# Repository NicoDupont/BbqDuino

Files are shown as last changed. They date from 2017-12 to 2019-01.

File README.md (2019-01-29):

## Arduino BbqDuino

Author : Nicolas Dupont  
Last Update : 14/01/2019  
Current state : **Prototype finished**  

The goal is to read, store and display the temperature of a barbecue/grill to follow the cooking.  
I hope it will be a very good friend for cooking sessions on my gaz barbecue.  

**To do List for final v1 ! :**  

1. Power supply the arduino from power bank
2. Electric card for integration
3. Fritzing
4. Make integration into a box
5. improve the arduino code and web app code
6. Add ifttt alert

**Features :**

- A WebApp to manage and monitor the cooking session.(the web app is designed to have just the necessary things)
- Monitor on the lcd the temperatures and the time ("partial" time can be reset with a button).
- A led indicate us if the food temperature is reached or if the barbecue temperature is not good (too low or too high).(+ IFTTT Alert)
- The 4 temperatures are stored in a database with a record every minutes.

**Start :**

Before to start the arduino. You need to asure you that the last cooking session is finished.    
Go to the webapp and see if it is already finished. If not push the End button at the bottom of the page.    
A message shows you that the session is now finished.  
Now add a new session by clicking on the weel at the top.  
Select what do you want and click on the button "Add or Edit".  
You go back automaticaly to the previous page and you see the informations about the new session.  
You can start the arduino now.  
The arduino ask to the server the informations about the last cooking session and after is going to send data to the server.  
The web page is reloaded automaticaly every 3 minutes but you can click on the refresh button at the top when you want to obtain the last data.  

**Folder organisation :**

	| BbqDuino
	  => | App ( SqlDatabase and WebApp(php,html,css,js) )
	     | Arduino  ( Arduino sketch and library )
	     | Img  ( Pictures of the bbqduino)
	     | Docs    ( Schematic / Diagram / Fritzing parts / Useful docs for the project )  
	     readme.md

**Code :**

Arduino : [sketch](https://github.com/NicoDupont/BbqDuino/blob/master/Arduino/bbqduino)  
WebApp : [Scripts](https://github.com/NicoDupont/BbqDuino/blob/master/App)  

To save data and to use the web app, you need a database and a php/web server.    
For the project I used :  

 - Debian 9 with Mariadb/Mysql, php7 and apache2 on a raspberry pi on my local network.
 - A web app (html/php/jquery) to visualize and manage all the data (backup, recovery and edit).
 - [Bootstrap](https://getbootstrap.com/) coupled with [ChartJs](http://www.chartjs.org/) to make the graph and the responsive design.

=> You need to adapt to your setting  

**Functional Diagram :**

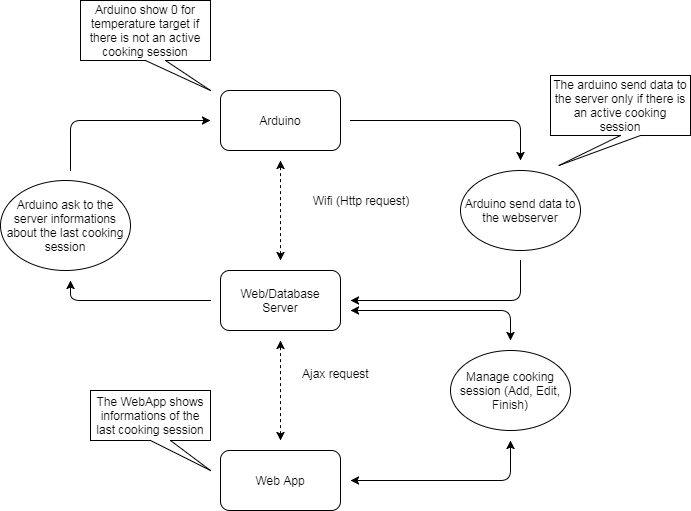
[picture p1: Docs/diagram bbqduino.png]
diagram bbqduino


**Parts used :**

 - NodeMcu esp12 
 - 4x maverick sensors ET-73 ([smoker](http://www.maverickhousewares.com/parts/et-73-smoker-probe),[food](http://www.maverickhousewares.com/parts/et-7273-high-heat-6ft-food-probe)) + 4x 22k omhs resistors
 - 1x DS18B20 digital sensor for the ambient temperature
 - 1x ADS1015 ADC I2C to connect the 4 maverick sensors because the nodemcu have only 1 analog input.
 - 1x 5mm leds + 1x 220 ohms resistors
 - 1x buttons + 1x 10k ohms resistors
 - 1x Lcd 16x2
 - 1x level shifter 3.3v/5v for the lcd witch is powered with 5v and not 3.3v [link](https://fr.aliexpress.com/item/Pratique-Simple-4-Canal-IIC-I2C-3-V-5-V-Logic-Level-Converter-Bidirektional-Shifter-Module/32839758085.html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)
 - 1x 3.3v regulator
 - 4x jack 2.5mm mono connector
 - 1x led 5mm support
 - 1x plastic box
 - 1x switch 2 positions to control the power supply
 - 1x usb mini pcb

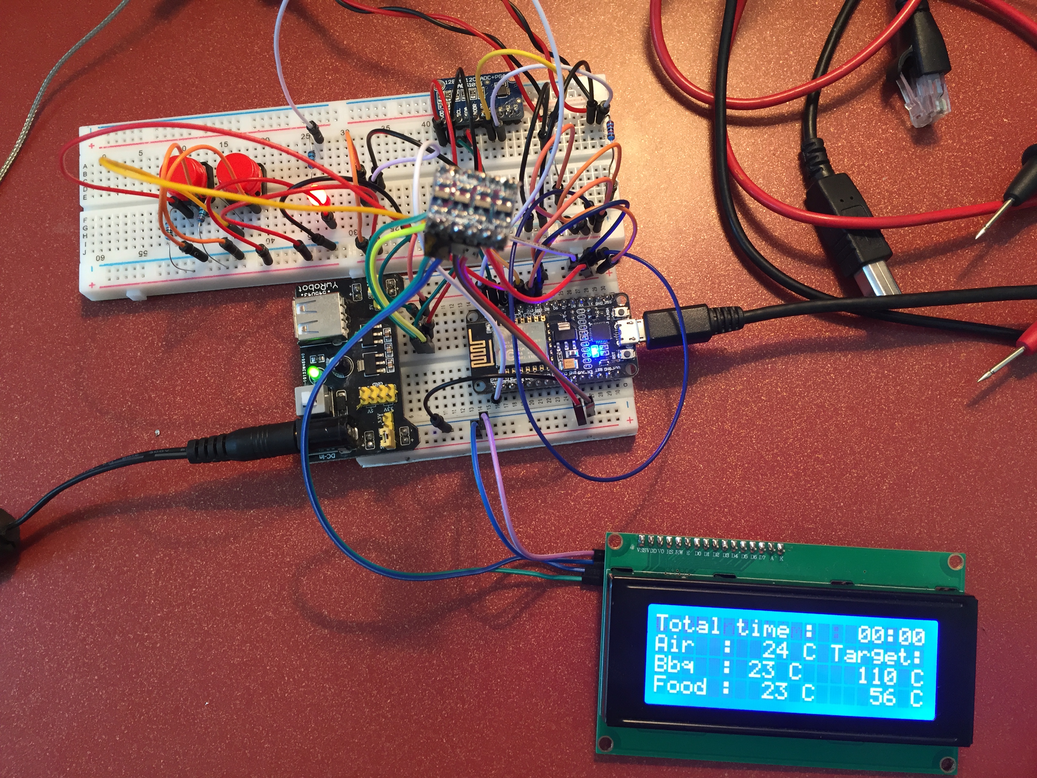
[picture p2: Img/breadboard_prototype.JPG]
parts1 bbqduino


**Web App :**

The web app is responsive :  

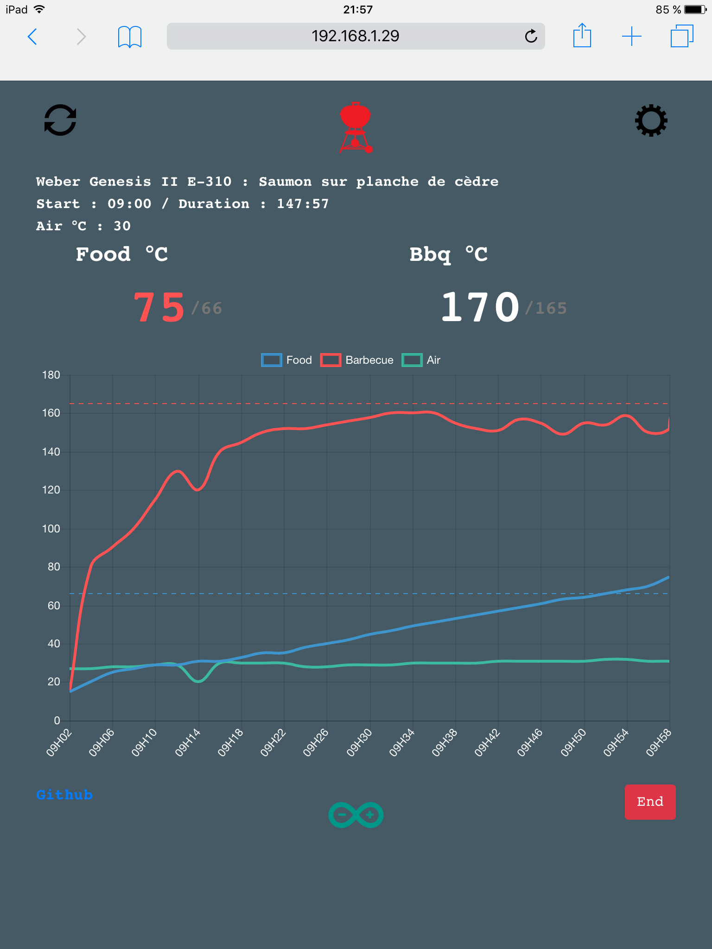
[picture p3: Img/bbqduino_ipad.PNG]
web app iphone6 bbqduino

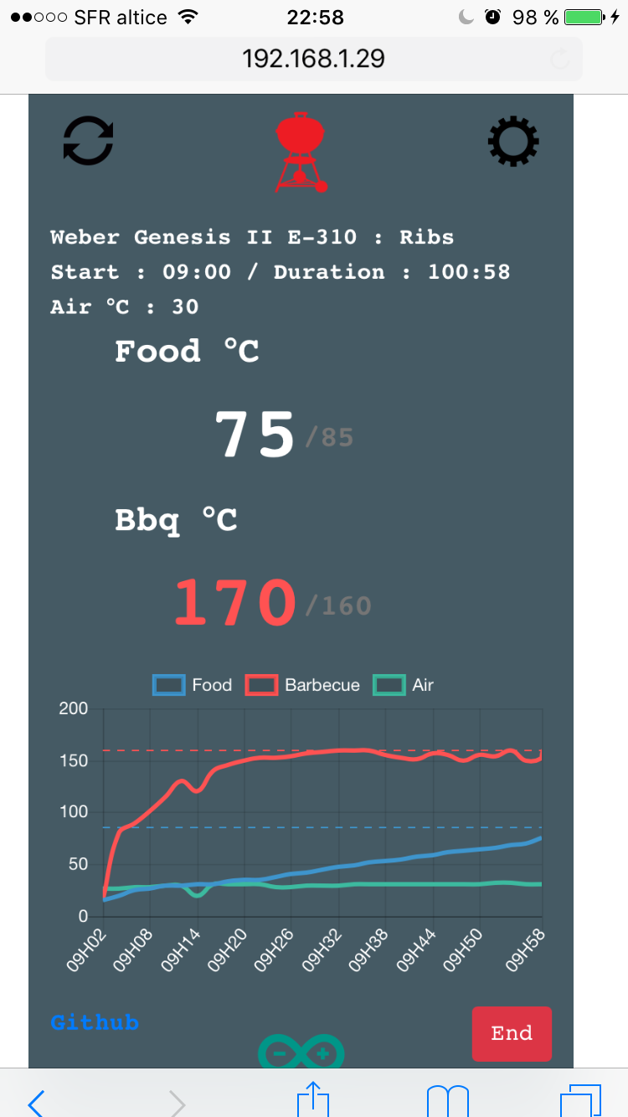
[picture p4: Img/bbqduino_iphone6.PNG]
web app ipad bbqduino


**Schematic :**

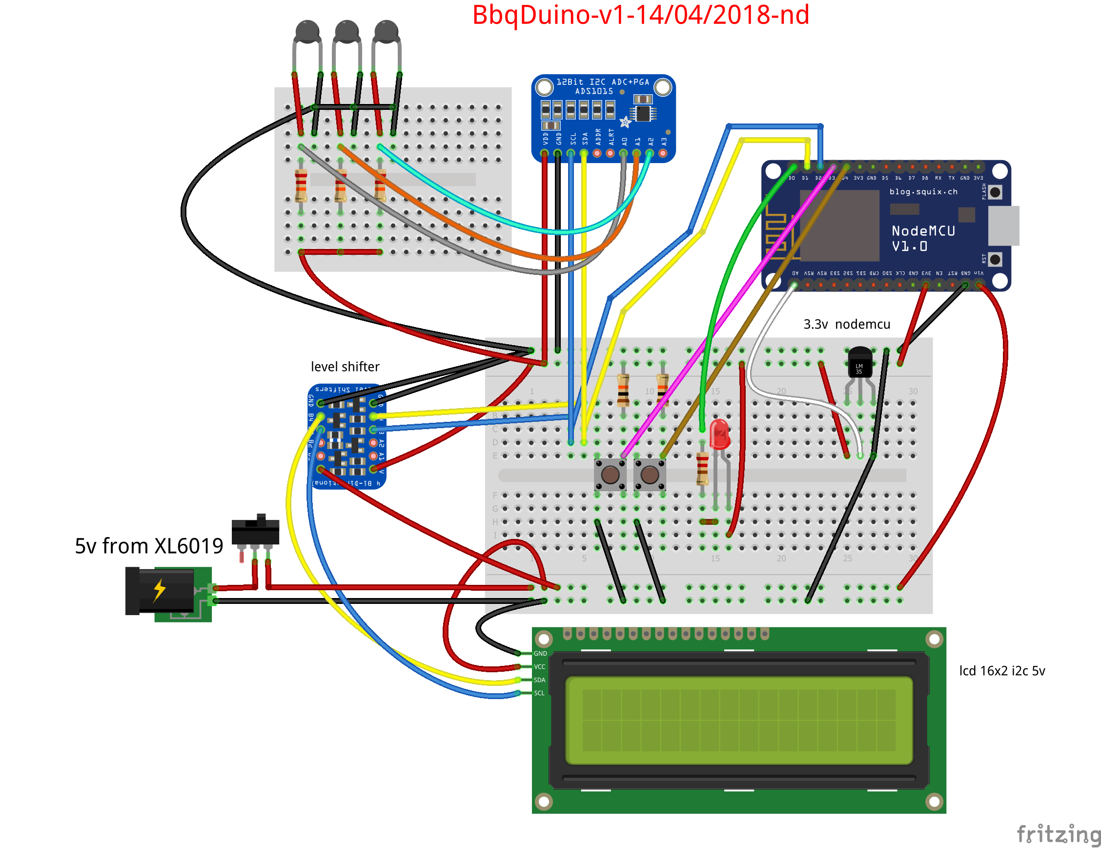
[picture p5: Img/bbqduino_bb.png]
fritzing bbqduino

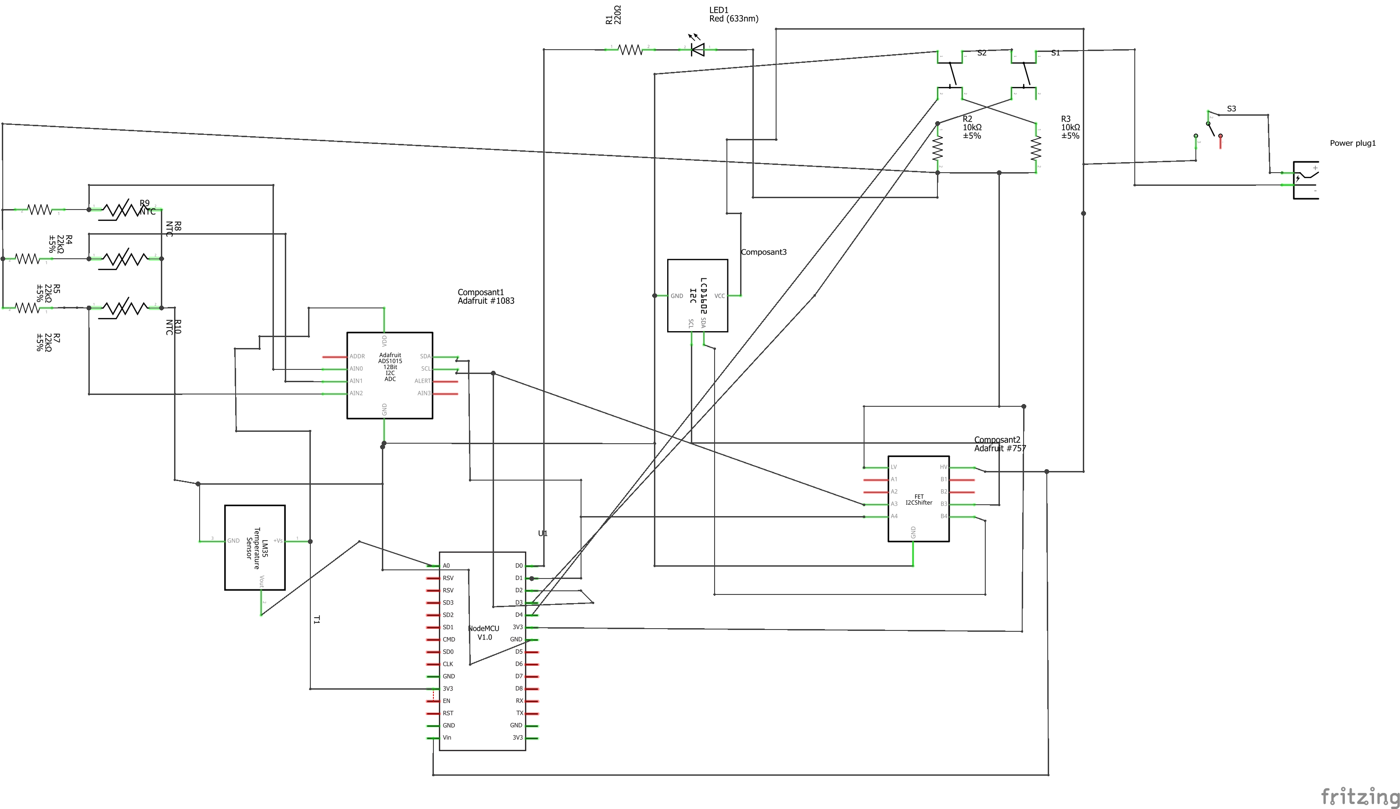
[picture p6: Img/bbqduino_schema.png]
elec bbqduino

board bbqduino

**Possible improvements :**

- Oled 128*64
- json data

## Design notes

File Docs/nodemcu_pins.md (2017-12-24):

- D0 = GPIO16;
- D1 = GPIO5;  => SDL  (I2C)
- D2 = GPIO4;  => SDA  (I2C)
- D3 = GPIO0;
- D4 = GPIO2;
- D5 = GPIO14;
- D6 = GPIO12;
- D7 = GPIO13;
- D8 = GPIO15;
- D9 = GPIO3; cannot be used
- D10 = GPIO1; cannot be used
- LED_BUILTIN = GPIO16 (auxiliary constant for the board LED, not a board pin);

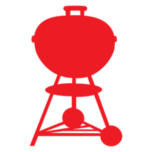
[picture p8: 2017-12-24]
App/BBQDUINO/img/bbqred.png

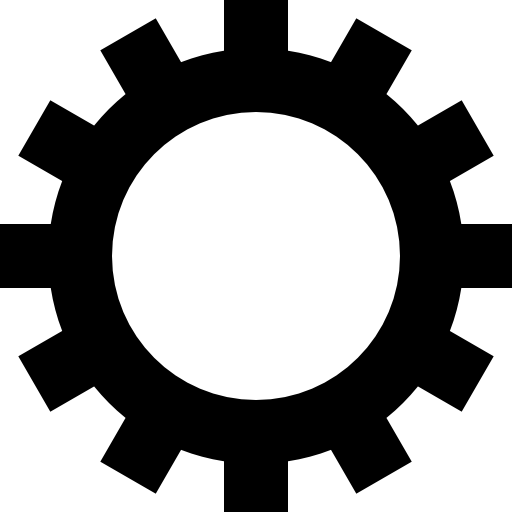
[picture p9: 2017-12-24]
App/BBQDUINO/img/wheel.png

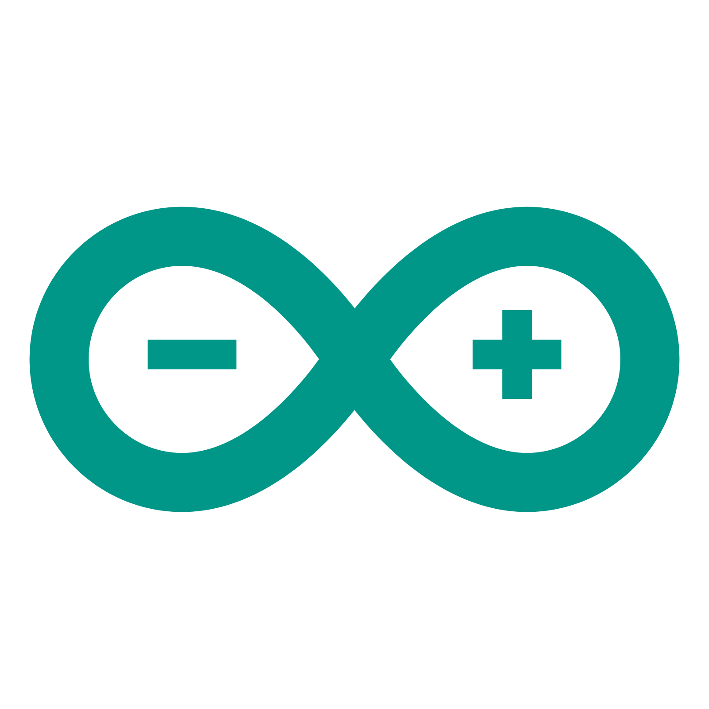
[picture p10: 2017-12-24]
App/BBQDUINO/img/arduino.png

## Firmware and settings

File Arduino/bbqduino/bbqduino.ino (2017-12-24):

/*
* -----------------------------------------------------------------------------------
* Last update :   24/12/2017
* Project BbqDuino v0
* Author(s) : Nicolas Dupont (https://github.com/NicoDupont)
* Contributor(s) :
* Arduino : Nodemcu esp12 + lcd 20x4 I2C + 2x buttons+ 2x maverick prob ET-73 + 1x lm35 + 1x ads1015
* Arduino 1.8.4 (Ubuntu 16.04.3)
* -----------------------------------------------------------------------------------
*/

//Library for I2C
#include <Wire.h> 

//Library for ads1015
#include <Adafruit_ADS1015.h>
Adafruit_ADS1015 ads1015;  // Ads1015 @ (0x48)

// Library for wifi
#include <ESP8266WiFi.h>
const char* ssid     = "YourSSID";			// Your SSID
const char* password = "YourPASSWORD";	// Your Password
const char* host = "Web/Databse Server Ip";				// Web/Databse Server Ip
const int httpPort = 80;						// Web/Databse Server port
WiFiClient client;								// Initialize the wifi client mode

// Library for LCD
#include <LiquidCrystal_I2C.h>
// Setup LCD I2C if the first one don't work try the second one
LiquidCrystal_I2C lcd(0x3F,20,4);		//LiquidCrystal_I2C lcd(0x27,20,4); 

// Setup the led 
const int L1 = 16;  						// pin D0 digital on the nodemcu
// Setup the buttons
const int BU1 = 0; 						// pin D3 digital
const int BU2 = 2;						// pin D4 digital
// Setup the buzzer
// const char BUZ = 15;						// pin D8 digital
// Setup variables
float voltage = 3.3;    				// 3.3 for the nodemcu esp12
long time0, time1, time2, time3, duration, total;	// manage the time in the main loop
int hour,minute,thour,tminute;			// display the cooking time on the lcd
boolean lcdtimeinfo, buzzer;			// toggle the display and the buzzer
const long tbrd = 15000; 				// time in ms between each update for session informations
const long tled = 4000;  				// time in ms between led and lcd control 
const long tber = 3000;  				// time in ms between each reading
const long tbgr = 60000; 				// 3600000=(1hour) time in ms between each geting request
const int idambient = 1; 				// id for the ambient prob
const int idbbq = 2;     				// id for the barbecue prob
const int idfood = 3;	 				// id for the food prob
const int idbbq2 = 4;             // id for the barbecue prob 2
const int idfood2 = 5;         // id for the food prob 2
int bbqtarget = 0;  	 				// temperature for the target internal barbecue temperature
const int bbqdelta = 7;  				// delta for led and buzzer control
int foodtarget = 0; 	 				// temperature for the target fooding temperature
const int fooddelta = 7; 				// delta for led and buzzer control
int tambient = 0;		 				// set ambient temperature at 0
int tbbq = 0; 			 				// set barbecue temperature at 0
int tfood = 0;			 				// set food temperature at 0
int tbbq2 = 0;               // set barbecue temperature at 0
int tfood2 = 0;              // set food temperature at 0
int sessionid = 0;		 				// set 0 for the session id 
int sessionend = 1;						// set 1 for the end state of the current session
// new structure for the http response
struct retrieve { int i, b, f, e; };
struct retrieve response;

/*-------------------------------------------------------
 * ------------------------------------------------------
 *   SETUP  *
 *-------------------------------------------------------
 --------------------------------------------------------*/
void setup(){

	Serial.begin(9600);					// Initialize the serial at 9600bauds

	StartLcd();							// Initialize the lcd
	StartWifi();						// Initialize the wifi connection
	IpSerialWifi();					// print local ip on serial monitor
	Serial.println("Init...");
	delay(1000); 
	Serial.println("Ready !");
	delay(1000); 						// wait a little
	MessageLcd(1, 3, "Starting..");
	MessageLcd(1, 4, "Ip:");
	lcd.setCursor(3,3);
	IpLcdWifi();						// print ip on the lcd
	delay(4000);						// wait a little
	//lcd.clear();						// Clear the lcd

	// initialize time for the main loop
	time0 = millis();
	time1 = millis();
	time2 = millis();
	time3 = millis();
	duration = millis();
	total = millis();
	lcdtimeinfo=0;						// toggle the display
	buzzer=0;							// toggle the buzzer
  
	// initialize pin output for the  led monitoring status
	pinMode(L1, OUTPUT);
	digitalWrite(L1, HIGH);
	//initialize the digital pins to use the 2 buttons
	pinMode(BU1, INPUT);
	pinMode(BU2, INPUT);
  
	UpdateData();						// get from the server : the last session id, the last target bbq temp, the last target food temp and the end state. 
  /*Serial.print("Session n° : ");
  Serial.println(sessionid);
  Serial.print("Session status n° : ");
  Serial.println(sessionend);*/
  
  //Serial.println("Getting single-ended readings from AIN0..3");
  //Serial.println("ADC Range: +/- 6.144V (1 bit = 3mV)");
  ads1015.begin();  // start the ads1015

}

/*-------------------------------------------------------
 * ------------------------------------------------------
 *   MAIN LOOP  *
 *-------------------------------------------------------
 --------------------------------------------------------*/
void loop(){

	/*
	Serial.print("Button 1 : ");
	Serial.println(digitalRead(BU1));
	Serial.print("Button 2 : ");
	Serial.println(digitalRead(BU2));
	*/
	// It will be better to use the button library or interrupt function.. but it work for now (it is very basic actualy)..  
	if ((digitalRead(BU1) == 1) && (digitalRead(BU2) == 0)){
		// reset duration (cooking time)
		duration = millis();
		delay(170);
	}
		else if ((digitalRead(BU1) == 0) && (digitalRead(BU2) == 1)){
		// reset total (total cooking time)
		total = millis();
		delay(170);
	}
  
	//-----------------------------------------------------------------------
	//-----------------------------------------------------------------------
	// Update the session informations from the server
	if((millis() - time3) >= tbrd) {
    if (TestWifi()){
      Serial.println("Restart Wifi connection !");
      StartWifi();
    }
		UpdateData();		// see the UpdateData() function for details
		time3 = millis();	//reboot time
	}
  
	//-----------------------------------------------------------------------
	//-----------------------------------------------------------------------
	// Update the 3 temperatures every << tber >> ms
	if((millis() - time1) >= tber) {
		tambient = (int) (analogRead(0) * (voltage / 1023.0 * 100.0)); // analog 0 on the nodemcu
		tbbq = AverageTemp(1,10); // anaolog 1 on ADS1015
		tfood = AverageTemp(0,10);// anaolog 0 on ADS1015
    //tbbq2 = AverageTemp(3,30); // anaolog 3 on ADS1015
    //tfood2 = AverageTemp(2,30);// anaolog 2 on ADS1015
		time1 = millis(); //reboot time
	}

	//---------------------------------------------------
	//---------------------------------------------------
	// Control when data needs to be send to the database
	if((millis() - time2) >= tbgr) { 
		// send data only if the session id is not equal to 0 and the current session is active
		if ((sessionid > 0) && (sessionend == 0)) {
			SaveDataWifi(sessionid,idambient,tambient);
			SaveDataWifi(sessionid,idbbq,tbbq);
			SaveDataWifi(sessionid,idfood,tfood);
      //SaveDataWifi(sessionid,idbbq2,tbbq2);
      //SaveDataWifi(sessionid,idfood2,tfood2);
		}
		time2 = millis(); //reset time
	}

  //-----------------------------------------------------------------------
  //-----------------------------------------------------------------------
  // Control the 3 leds, the buzzer and the lcd 
  if((millis() - time0) >= tled) {

		//-------------------
		// Send the 3 temperatures to the serial monitor
		Serial.print("Air : ");
		PrintTemp(tambient);
		Serial.print("Bbq : ");
		PrintTemp(tbbq);
		Serial.print("Food : ");
		PrintTemp(tfood);

		//-------------------
		// Control the buzzer if necessary
    //Serial.print("State Alertemp : ");
    //Serial.println(AlertTemp(tbbq,tfood,tbbq2,tfood2));
		/*if (AlertTemp(tbbq,tfood,tbbq2,tfood2)){
			//Serial.print("buzzer : ");
			//Serial.println(buzzer);
			if(buzzer == 1){     
				tone(BUZ,500);
        delay(300);
        noTone(BUZ);
				delay(500);
				tone(BUZ,500);
        delay(300);
        noTone(BUZ);
			}
		}*/

		//-------------------
		// Update lcd and toggle CookingTime/totaltime
		lcd.clear();
		
		if (lcdtimeinfo == 0){
			//-------------------
			// update the cooking time
			hour=DurationHour(duration);
			minute=DurationMinute(duration);
			
			MessageLcd(1,1,"Cooking time : ");
			lcd.setCursor(15,0);
			if (hour < 10) {
				lcd.print("0");
				lcd.print(hour);
			}else{
				lcd.print(hour);
			}
			lcd.print(":");
			if (minute < 10){
				lcd.print("0");
				lcd.print(minute);
			}else{
				lcd.print(minute);
			}
		}else{
			//-------------------
			// update the total time
			thour=DurationHour(total);
			tminute=DurationMinute(total);

			MessageLcd(1,1,"Total time : ");
			lcd.setCursor(15,0);
			if (thour < 10) {
			lcd.print("0");
			lcd.print(thour);
			}else{
			lcd.print(thour);
			}
			lcd.print(":");
			if (tminute < 10) {
			lcd.print("0");
			lcd.print(tminute);
			}else{
			lcd.print(tminute);
			}
		}
    
		PrintTempLcd(tambient,"Air  :  ",1,2);
		MessageLcd(14,2,"Target:");
		PrintTempLcd(tbbq,"Bbq  : ",1,3);
		PrintTempLcd(tfood,"Food :  ",1,4);
		lcd.setCursor(15,2);
		lcd.print(bbqtarget);
		lcd.print(" C");
		lcd.setCursor(16,3);
		lcd.print(foodtarget);
		lcd.print(" C");

		//----------------------
		// Toggle the state of the led 
		if (AlertTemp(tbbq,tfood,tbbq2,tfood2)){   
			if (digitalRead(L1)){
				digitalWrite(L1, LOW);
			}
		}else{ 
			if (!digitalRead(L1)) {
				digitalWrite(L1, HIGH);
			}
		}
		time0 = millis();			//reset time
		lcdtimeinfo = !lcdtimeinfo;	// toggle 
		buzzer = !buzzer;			// toggle 
   
	}

} //end main loop


/*-------------------------------------------------------
 * ------------------------------------------------------
 *   FUNCTIONS   *
 *-------------------------------------------------------
 --------------------------------------------------------*/

void PrintTemp(float temp){
	Serial.print(temp);
	Serial.println(" : Degrés Celcius");
}

void PrintTempLcd(int temp, char text[], int posi, int line){
	lcd.setCursor(posi-1,line-1);
	lcd.print(text);
	lcd.print(temp);
	lcd.print(" C");  
}

void StartWifi(){
	//Serial.print("Connecting to ");
	//Serial.println(ssid);
	WiFi.begin(ssid, password); 
  int i =0;
	while (WiFi.status() != WL_CONNECTED){
		delay(500);
		Serial.print(".");
    i++;
    if (i >= 20){
      break;
      }
	}
	Serial.println("WiFi connected");  
	//Serial.println("IP address: ");
	//Serial.println(WiFi.localIP());	
}

// not tested
bool TestWifi(){
	if (WiFi.status() != WL_CONNECTED){
		return 0;
	}else{
		return 1;
	}
}

void IpSerialWifi(){
	Serial.print("My IP address: ");
	Serial.print(WiFi.localIP());
	Serial.print(".");
	Serial.println();
}

void SaveDataWifi(int s, int id, int temp){
	//Serial.print("connecting to ");
	//Serial.println(host);
	if (client.connect(host, httpPort)){
		// We now create a URI for the request
		String url = "/BBQDUINO/savedata.php";
		url += "?session=";
		url += (int) s;
		url += "&id=";
		url += (int) id;
		url += "&temp=";
		url += (int) temp;
		//Serial.println(url);
		client.print(String("GET ") + url + " HTTP/1.1\r\n" +
					 "Host: " + host + "\r\n" + 
					 "Connection: close\r\n\r\n");
		//delay(100);
		client.stop();
	}else{
		//StartWifi();
	}
}

  
void StartLcd(){  
	lcd.init();          
	lcd.backlight();
	lcd.setCursor(0,0);
	lcd.print("----- BBQDUINO -----");
	lcd.setCursor(0,1);
	lcd.print("v0 ------ 24/12/2017");
}

void MessageLcd(int posi, int line,char message[]){
	lcd.setCursor(posi-1,line-1);
	lcd.print(message); 
}


void IpLcdWifi() {
	lcd.print(WiFi.localIP()); 
	lcd.print(".");	
}

int DurationHour(long dur){
	long h;
	h= (millis() - dur) / 3600000;
	return (int) (h);
}

int DurationMinute(long dur){
	long m, h;
	h = DurationHour(dur);
	m= (millis() - dur - (h*3600000)) / 60000;
	return (int) (m);
}

int maverick_temp(int aval){
  double R, T;
  // Function from : http://smokingmeatforums.com/index.php?threads/the-how-to-for-making-an-arduino-controlled-smoker.90085/
  // These were calculated from the thermister data sheet
  //  A = 2.3067434E-4;
  //  B = 2.3696596E-4;
  //  C = 1.2636414E-7;
  // This is the value of the other half of the voltage divider
  R = log((1 / ((1023 / (double) aval) - 1)) * (double) 22500);
  // Compute degrees C
  T = (1 / ((2.3067434E-4) + (2.3696596E-4) * R + (1.2636414E-7) * R * R * R)) - 273.25;
  return (T);
}

int AverageTemp(int analogpin,int nb){
  int SumTemp = 0;
  int i = 0;
  while(i < nb){
    SumTemp += (int) (maverick_temp((ads1015.readADC_SingleEnded(analogpin) * 0.003 / voltage) * 1023));
    delay(10);
    //Serial.println(i);
    i++;
  }
  return (int) (SumTemp / nb);
}

bool AlertTemp(int tempbbq,int tempfood,int tempbbq2,int tempfood2){	
	if ((tempbbq == 0) || (tempfood ==0) || (bbqtarget == 0)  || (foodtarget == 0) /*|| (tempbbq2 == 0) || (tempfood2 == 0)*/){
		return 0;
	}else if ((tempbbq < (bbqtarget - bbqdelta)) || (tempbbq > (bbqtarget + bbqdelta)) || (tempfood > (foodtarget - fooddelta)) /*|| (tempbbq2 < (bbqtarget - bbqdelta)) || (tempbbq2 > (bbqtarget + bbqdelta)) || (tempfood2 > (foodtarget - fooddelta))*/){
		return 1;
	}else{
		return 0;
	}	
}


void UpdateData(){
	response = RetrieveData();
	while ((response.i == 0) || (response.i > 1000) || (response.b == 0) || (response.b > 1000) || (response.f == 0) || (response.f > 1000) || (response.e > 1)){ 
		Serial.println('Problem');
		response = RetrieveData();
	}
	sessionid = response.i;
	bbqtarget = response.b;
	foodtarget = response.f;
	sessionend = response.e; 
}

retrieve RetrieveData(){
	int d[] = {0, 0, 0, 0};
	if (client.connect(host, httpPort)){
		String url = "/BBQDUINO/retrievedata.php";
		client.print(String("GET ") + url + " HTTP/1.0\r\n" +
					"Host: " + host + "\r\n" + 
					"Connection: close\r\n\r\n");
		while (client.available() == 0){
			//wait client.available() == 0
		} 
		String text = "";    
		while(client.available()){
			char r = client.read();
			//Serial.println(r);
			text += r;
		}
		client.stop();
		//Serial.println(text);
		char chartext[text.length() + 1];
		text.toCharArray(chartext, text.length());
		char dlm[] = "|";
		char* val;
		val = strtok(chartext, dlm);
		for(int i = 0; i < 5; i++){
			d[i] = atoi(val);
			//Serial.println(d[i]);
			val = strtok(NULL, dlm);
		}
	}
	else{
		//StartWifi();
	}
	return { d[1], d[2], d[3], d[4] }; 
}
